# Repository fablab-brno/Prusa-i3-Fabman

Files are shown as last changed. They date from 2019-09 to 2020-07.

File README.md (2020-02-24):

# Prusa i3 Fabman

This repository is mostly dedicated to custom Fabman hardware for Prusa i3 printers.

Fabman.io is all-in-one makerspace management solution and this HW use this service to send amount of filament, name of the file and time of the print to this service. 

This HW was developed by FabLab Brno. You can learn more about our journey <a href="https://hackaday.io/project/166410-access-system-for-3d-printers" target="_blank">here</a>.

We can provide you with complete kit of this HW or you can make your own. All files for production are in this repo. 

We do not share source code for our firmware, but you can easily set it up with you creadentials for Fabman.io . We supply our HW with simple FW which allows you to set things up.    

For this, we use following JSON file: 

```json
{
  "config": {
    "API_key": "device_API_key_from_fabman.io",
	"API_key_master":"admin_API_key_from_fabman.io",
    "nameOfMachine": "custom_name_of_the_machine", 
	"sendName": true,
	"sendFilament": true,
	"sendTime": false,
	"resetSettings": false, 
	"firstSettings": true
  },
  "WiFi": [
    {
      "SSID": "some_wifi",
      "password": "some_password"
    },{
      "SSID": "some_wifi",
      "password": "some_password"
    }
  ]
}
```

For more detailed information, please look at wiki.

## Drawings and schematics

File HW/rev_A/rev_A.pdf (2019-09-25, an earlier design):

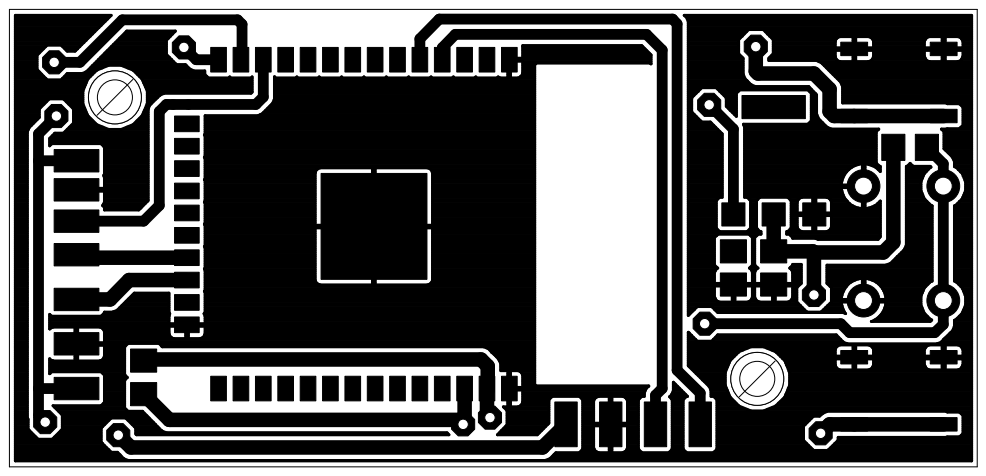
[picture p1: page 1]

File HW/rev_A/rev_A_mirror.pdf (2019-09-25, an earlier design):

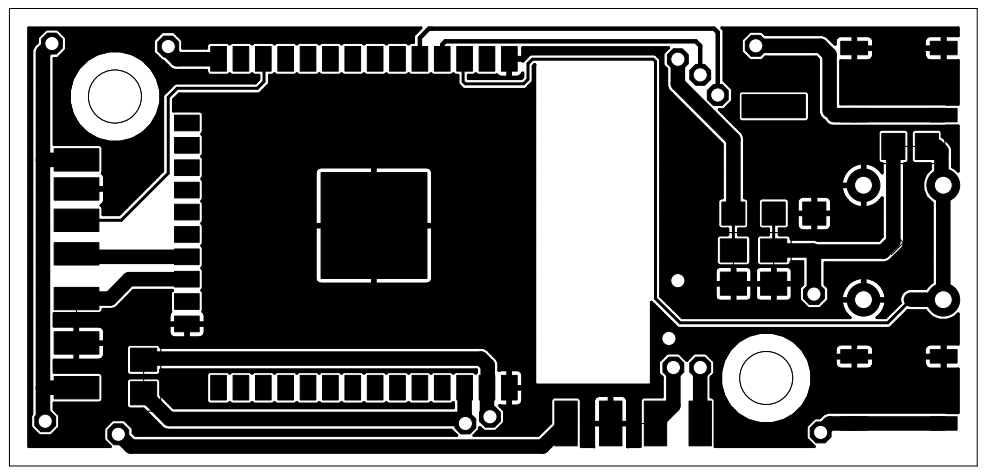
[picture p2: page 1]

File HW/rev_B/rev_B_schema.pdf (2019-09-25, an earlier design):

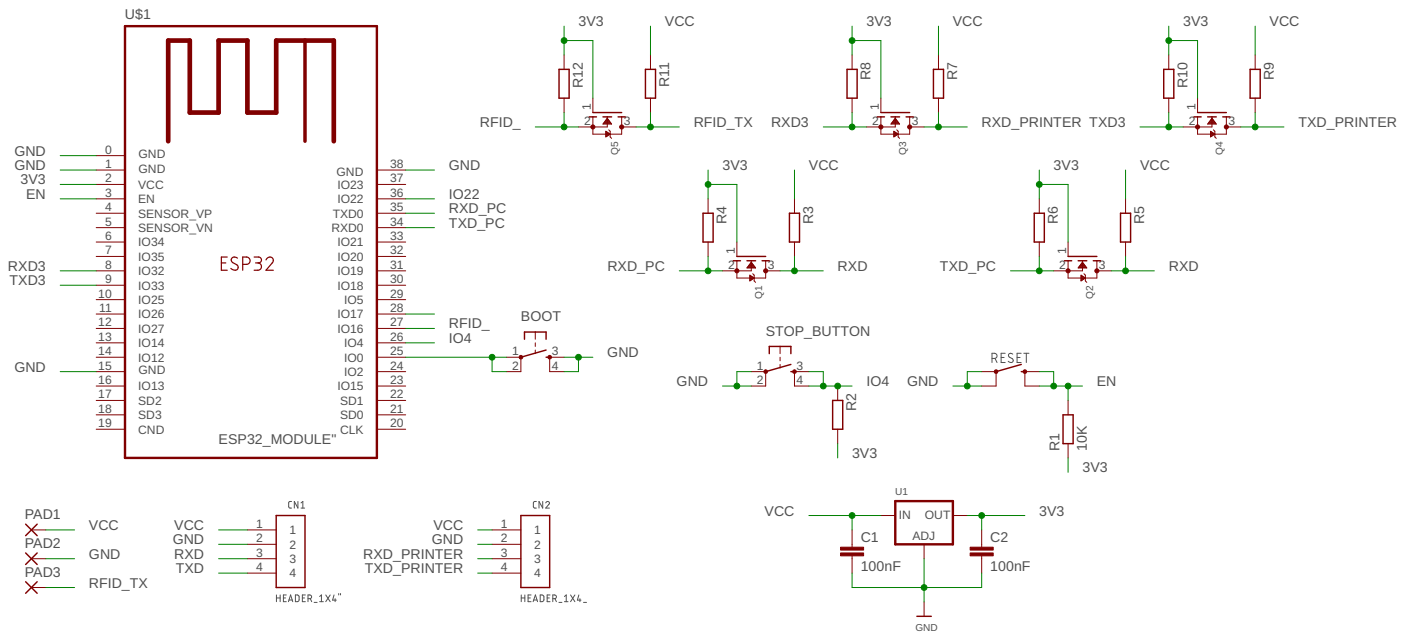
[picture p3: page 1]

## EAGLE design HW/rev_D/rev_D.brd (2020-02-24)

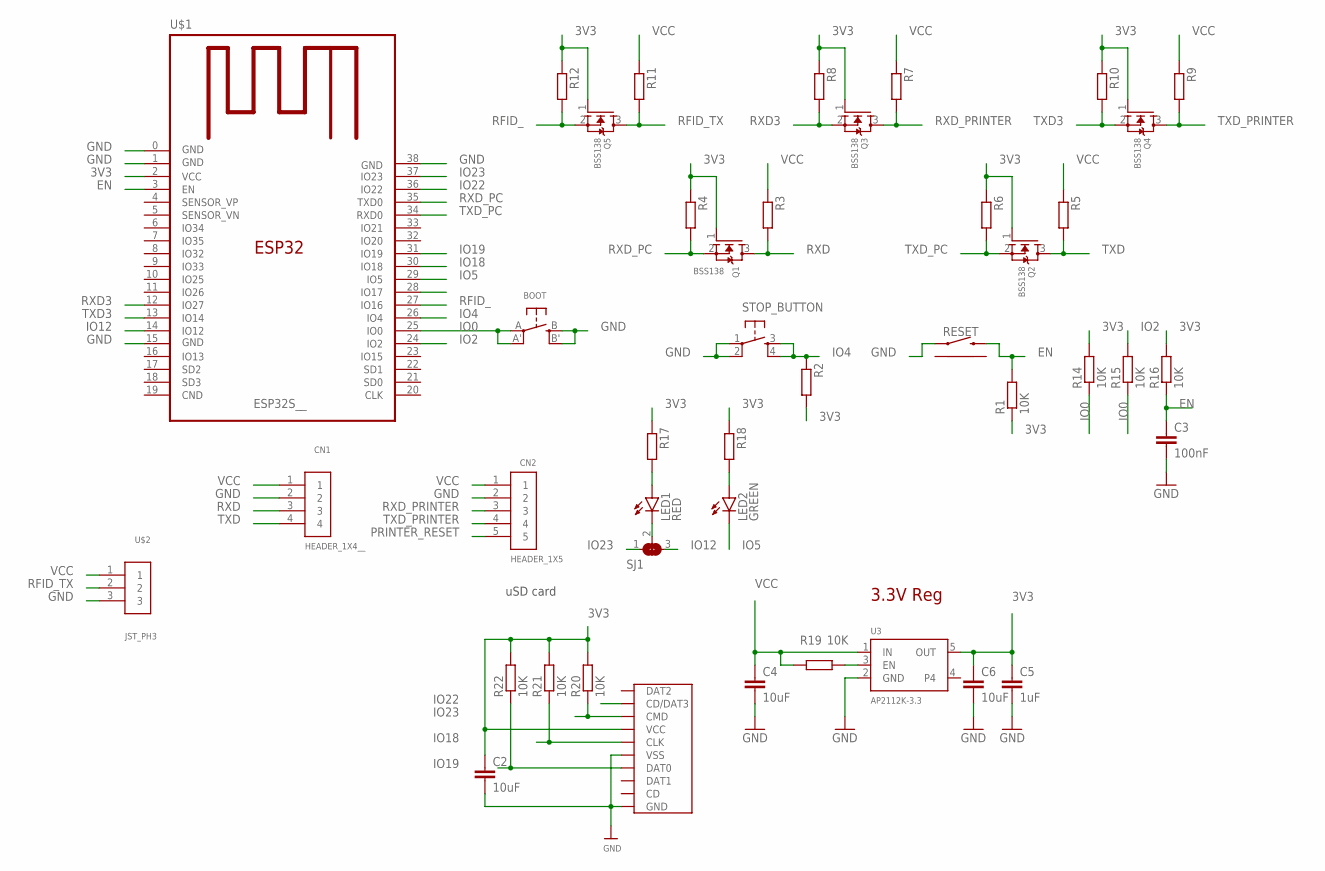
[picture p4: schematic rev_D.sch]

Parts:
BOOT: BUTTON_KMR2_4.6X2.8
C2, C4, C6: 10uF; C0805
C3: 100nF; C0805
C5: 1uF; C0805
CN1: HEADER_1X4__; HEADER_1X4_RIGHT_ANGLE
CN2: HEADER_1X5
LED1: RED; CHIP-LED0805
LED2: GREEN; CHIP-LED0805
Q1, Q2, Q3, Q4, Q5: BSS138; SOT95P240X110-3
R1, R2, R3, R4, R5, R6, R7, R8, R9, R10, R11, R12, R14, R15, R16, R19, R20, R21, R22: 10K; R0805
R17, R18: 470R; R0805
RESET: TACTILE_SWITCH_RIGHT_ANGLE_THT_; TACTILE_SWITCH_RIGHT_ANGLE_THT
SD_CARD: MICRO_SD_CARD_; TFP09-2--12B
SJ1: SOLDERJUMPER_2WAY0805; SOLDERJUMPER_2WAY_OPEN_0805
STOP_BUTTON: TACTILE_SWITCH_LONG_THT_; TACTILE_SWICTH_THT
U3: AP2112K-3.3; SOT95P290X120-5
U$1: ESP32S__; ESP32S
U$2: JST_PH3; JST-PH3

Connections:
3V3: C2.1, C5.1, C6.1, Q1.1 (G), Q2.1 (G), Q3.1 (G), Q4.1 (G), Q5.1 (G), R1.1, R2.2, R4.1, R6.1, R8.1, R10.1, R12.1, R14.2, R16.2, R17.1, R18.1, R20.2, R21.2, R22.2, SD_CARD.VCC, U3.5 (OUT), U$1.2 (VCC)
EN: C3.1, R1.2, R16.1, RESET.2, U$1.3 (EN)
GND: BOOT.B (S), BOOT.B' (S1), C2.2, C3.2, C4.2, C5.2, C6.2, CN1.2, CN2.2, RESET.1, SD_CARD.GND, SD_CARD.GND@1 (GND), SD_CARD.GND@2 (GND), SD_CARD.GND@3 (VSS), SD_CARD.VSS (GND), STOP_BUTTON.1, STOP_BUTTON.2, U3.2 (GND), U$1.0 (GND), U$1.1 (GND), U$1.15 (GND), U$1.38 (GND), U$2.3
IO0: BOOT.A, BOOT.A' (P1), R14.1, R15.1, U$1.25 (IO0)
IO2: R15.2, U$1.24 (IO2)
IO4: R2.1, STOP_BUTTON.3, STOP_BUTTON.4, U$1.26 (IO4)
IO5: LED2.C, U$1.29 (IO5)
IO12: SJ1.3, U$1.14 (IO12)
IO18: R21.1, SD_CARD.CLK, U$1.30 (IO18)
IO19: R22.1, SD_CARD.DAT0, U$1.31 (IO19)
IO22: SD_CARD.CD/DAT3, U$1.36 (IO22)
IO23: R20.1, SD_CARD.CMD, SJ1.1, U$1.37 (IO23)
unnamed: LED1.C, SJ1.2
unnamed: LED1.A, R17.2
unnamed: LED2.A, R18.2
unnamed: R19.2, U3.3 (EN)
PRINTER_RESET: CN2.5
RFID_: Q5.2 (S), R12.2, U$1.27 (IO16)
RFID_TX: Q5.3 (D), R11.2, U$2.2
RXD: CN1.3, Q1.3 (D), R3.2
RXD3: Q3.2 (S), R8.2, U$1.12 (IO27)
RXD_PC: Q1.2 (S), R4.2, U$1.35 (TXD0)
RXD_PRINTER: CN2.3, Q3.3 (D), R7.2
TXD: CN1.4, Q2.3 (D), R5.2
TXD3: Q4.2 (S), R10.2, U$1.13 (IO14)
TXD_PC: Q2.2 (S), R6.2, U$1.34 (RXD0)
TXD_PRINTER: CN2.4, Q4.3 (D), R9.2
VCC: C4.1, CN1.1, CN2.1, R3.1, R5.1, R7.1, R9.1, R11.1, R19.1, U3.1 (IN), U$2.1

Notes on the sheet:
3.3V Reg
uSD card

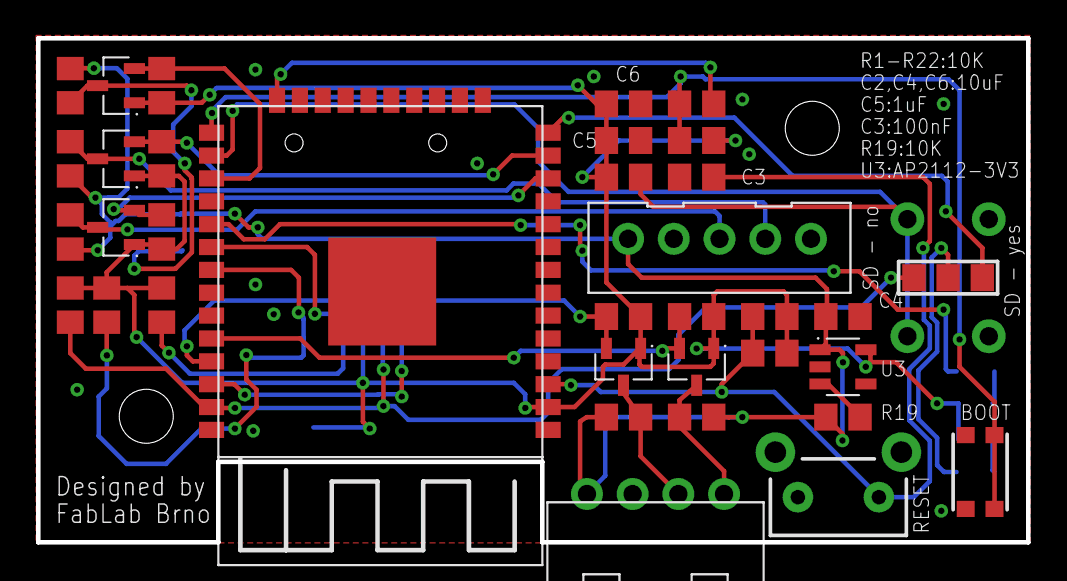
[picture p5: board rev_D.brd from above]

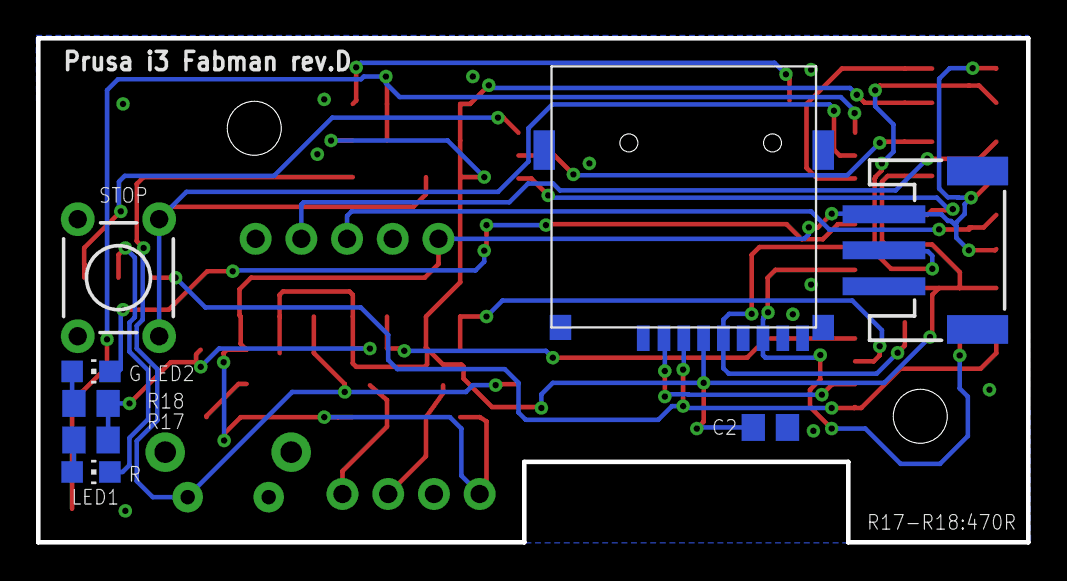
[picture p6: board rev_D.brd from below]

Board: 2 copper layers, 55.0 x 28.0 mm, 43 parts (8 on the bottom side), 27 nets.

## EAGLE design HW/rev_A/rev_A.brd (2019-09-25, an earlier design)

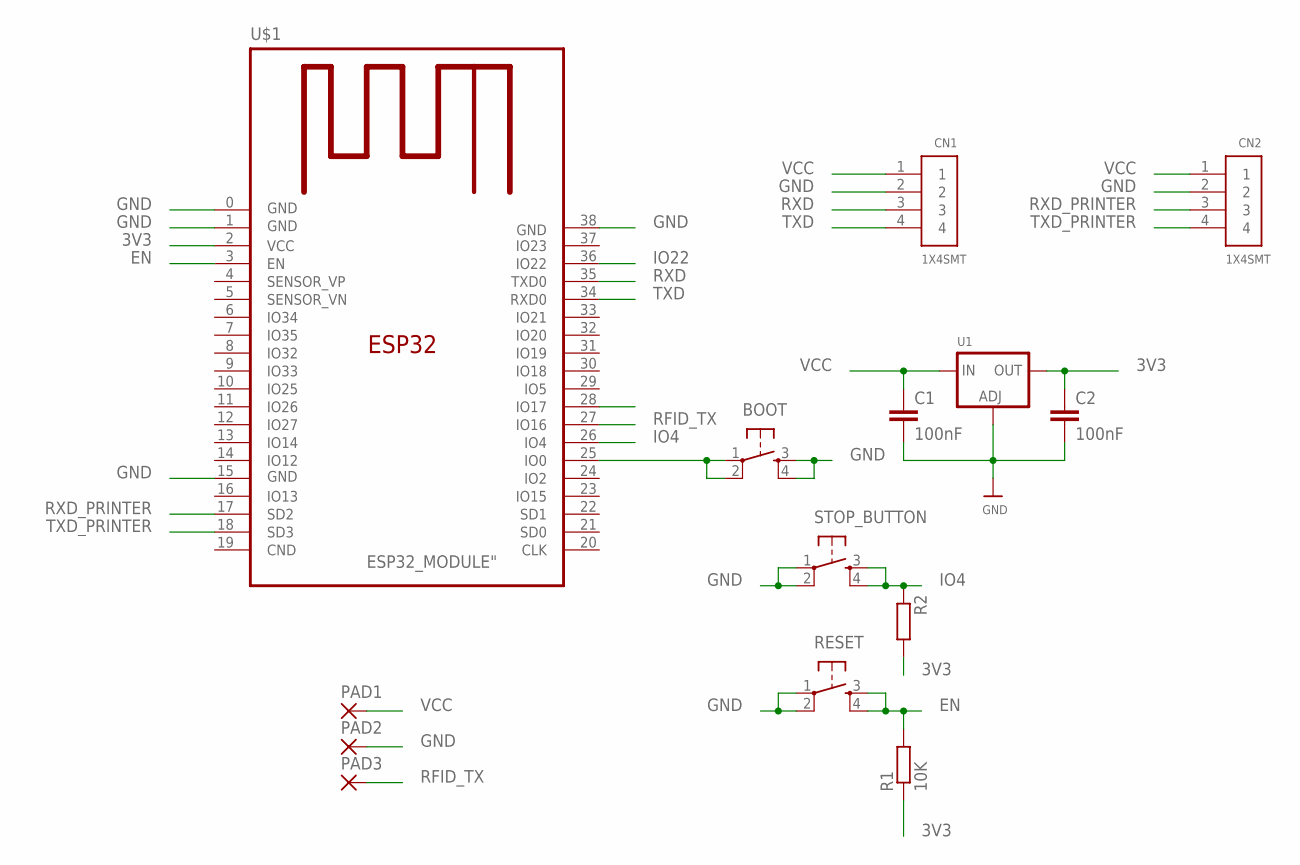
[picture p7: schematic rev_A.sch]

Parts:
BOOT: TACTILE_SWITCHE_5X5_MICRO"; TACTILE_SWITCH_5X5_MICRO
C1, C2: 100nF; C0805
CN1, CN2: 1X4SMT; 1X4-SMT
PAD1, PAD2, PAD3: SMD2; SMD1,27-2,54
R1, R2: 10K; R0805
RESET: TACTILE_SWITCHE_5X5_MICRO"; TACTILE_SWITCH_5X5_MICRO
STOP_BUTTON: TACTILE_SWITCH_THT_; TACTILE_SWICTH_THT
U1: LM1117SOT223-REFLOW; SOT223-R
U$1: ESP32_MODULE"; ESP32_MODULE

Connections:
3V3: C2.1, R1.1, R2.2, U1.2 (OUT), U$1.2 (VCC)
EN: R1.2, RESET.3, RESET.4, U$1.3 (EN)
GND: BOOT.3, BOOT.4, C1.2, C2.2, CN1.2, CN2.2, PAD2.1, RESET.1, RESET.2, STOP_BUTTON.1, STOP_BUTTON.2, U1.1 (ADJ), U$1.0 (GND), U$1.1 (GND), U$1.15 (GND), U$1.38 (GND)
IO4: R2.1, STOP_BUTTON.3, STOP_BUTTON.4, U$1.26 (IO4)
IO22: U$1.36 (IO22)
unnamed: BOOT.1, BOOT.2, U$1.25 (IO0)
RFID_TX: PAD3.1, U$1.27 (IO16)
RXD: CN1.3, U$1.35 (TXD0)
RXD_PRINTER: CN2.3, U$1.17 (SD2)
TXD: CN1.4, U$1.34 (RXD0)
TXD_PRINTER: CN2.4, U$1.18 (SD3)
VCC: C1.1, CN1.1, CN2.1, PAD1.1, U1.3 (IN)

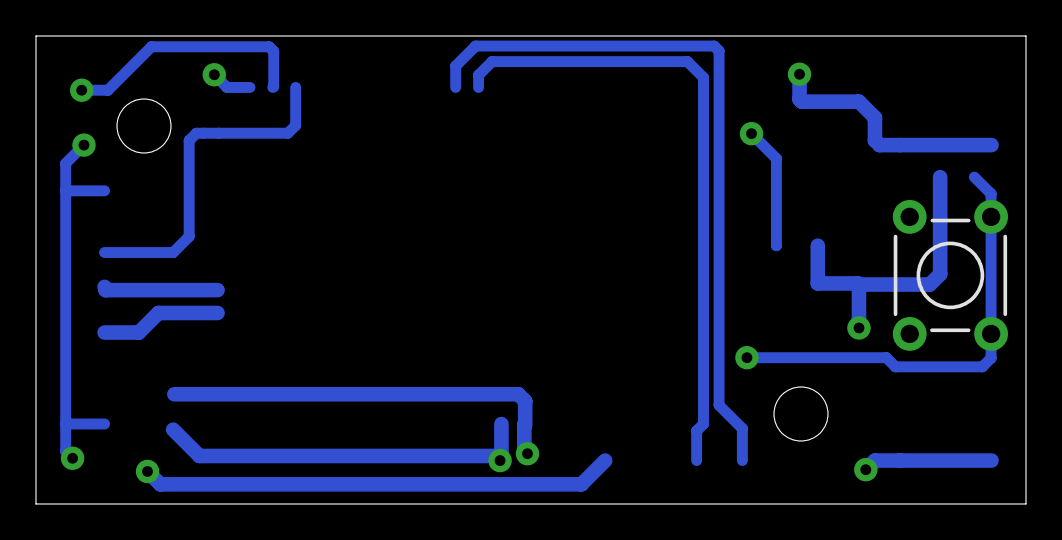
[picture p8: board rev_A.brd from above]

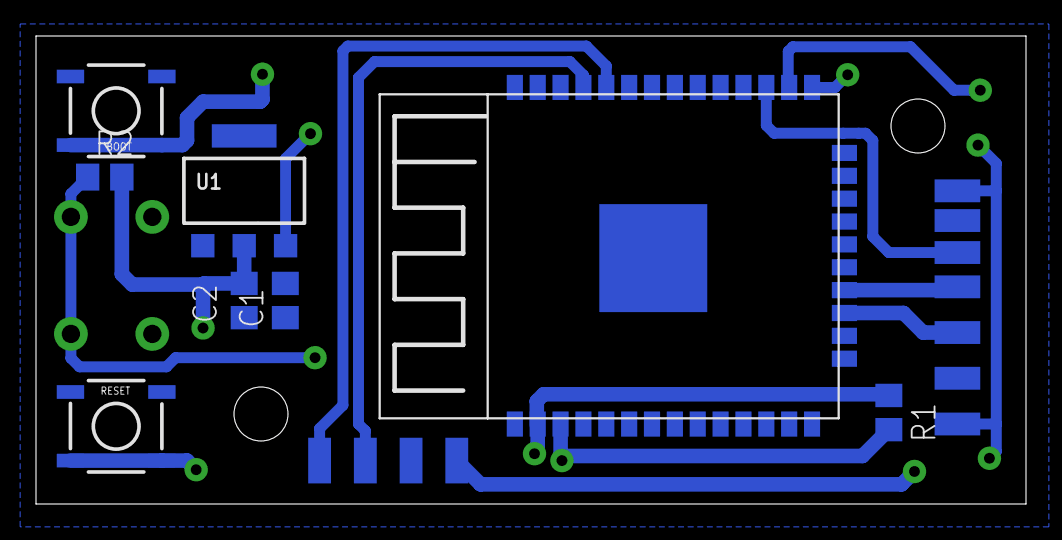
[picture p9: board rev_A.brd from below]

Board: 2 copper layers, 55.0 x 26.0 mm, 14 parts (13 on the bottom side), 11 nets.

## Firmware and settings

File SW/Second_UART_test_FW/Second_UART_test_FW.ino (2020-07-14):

HardwareSerial secondSerial(1);

void setup() {
  Serial.begin(115200);
  secondSerial.begin(115200, SERIAL_8N1, 14, 27);
}

void loop() {
  if (secondSerial.available() > 0) {
    String data = secondSerial.readStringUntil('\n');
    if (data == "Data from RPi") {
      secondSerial.println("Test");
      Serial.println("Comunnication work both way!");
    }
  }
}

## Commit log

2019-09-25 Initial commit
    upload of all version
    [rev_A.brd, rev_A.sch, rev_B.brd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]
2020-02-24 Files clean up & README update
    [rev_D.brd, rev_D.sch]

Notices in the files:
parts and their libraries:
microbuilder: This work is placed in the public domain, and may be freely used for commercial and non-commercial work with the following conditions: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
